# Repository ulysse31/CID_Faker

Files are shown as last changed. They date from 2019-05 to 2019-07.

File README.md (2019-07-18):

# DISCLAIMER :
# THIS PROJECT IS A PATCH MADE BY MYSELF, FOR MYSELF, AND IT AIMS TO COMPENSATE, THE LACK OF BUG CORRECTIONS IN THIRD PARTY REPLACEMENT SCREENS (CHINESE ANDROID BASED SCREENS) THAT DO NOT HAVE IMPLEMENTED THIS PARTICULAR CASE ON THEIR MCU FIRMWARE...

# WARNING !!! WE ARE TALKING ABOUT INJECTING DATA TO THE CAR NETWORK, THIS IS AT YOUR OWN RISK !!! I WILL NOT BE RESPONSIBLE FOR ANY HARM YOU MAY CAUSE TO YOUR CAR, YOURSELF, OR ANY OTHER
# YOU HAVE BEEN WARNED !!!
# CID_Faker
A CID can bus simulator:

CID (Central Information Display) on BMW cars from 2004 to 2011 is the designation for the car LCD screen.
Some of those screens are connected to the can bus of the car (at least BMW flap screens).
If you try to replace this type of screen with something else (like an Android Head Unit) you'll loose the ability to 
interact with the BMW original menu (no actions from idrive interpreted).

This project supposes that this is because of the absence of the can message id from the screen : "why take into
account moves from idrive if no screen detected" ... thats what the engineer may have thought when implementing this
on the CCC controller ...

This little code will so generate fake CID id messages on the can bus of the car, to simulate the presence of the CID.
CID sends messages with id 0x33a (status) and 0x4f3 (network).
All the main job will be to find the right messages, their combinations and timings.

Project uses platformIO for easy compilation and development.

For now, I'm using a Pro Micro board 5V@16Mhz, and a well known MCP2515 CAN Controller module, more precisely the
MCP2515 CAN controller with a 8Mhz oscillator and TJA1050 CAN transceiver.

You'll find on "Hardware" folder 2 types of designs :

- USB_Powered (tested working/recommended): this light version aims to be connected to the Android HU on its USB port, allowing it to be
powered up once the Android is up (key car inserted), and powered off when Android goes off (key car taken out)

- Standalone (not tested/under construction): this version aims to be more "unrelated" the Android HU, it is up the user to find a power
cable source from the car (preferrably, a source that is NOT always on ...)

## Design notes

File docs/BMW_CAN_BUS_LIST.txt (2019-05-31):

CAN_ID_HEX	CAN_ID_NAME	CAN_ID_NAME (Translated)	DIAG_ID_HEX	SG_NAME
0x00	unbekannt	unknown	0x00	Sender unbekannt
0xA8	Drehmoment 1 K-CAN [10]	Torque 1 K-CAN [10]	0x12	DME1/DDE1
0xA9	Drehmoment 2 (10)	Torque 2 (10)	0x12	DME1/DDE1
0xAA	Drehmoment 3 K-CAN [10]	Torque 3 K-CAN [10]	0x12	DME1/DDE1
0xAC	Radmoment Antriebsstrang 2 [5]	Wheel torque Drive train 2 [5]	0x12	DME1/DDE1
0xAD	Verzögerungsanforderung ACC [9]	Delay request ACC [9]	0x1C	LDM
0xAD	Verzögerungsanforderung ACC [9]	Delay request ACC [9]	0x21	ACC_Modul/ACC+NAVI
0xB3	Steuerung Lenkunterstützung [2]	Steering assistance steering [2]	0x16	AFS
0xB4	Radmoment Antriebsstrang 1 [4]	Wheel torque Drive train 1 [4]	0x12	DME1/DDE1
0xB5	Drehmomentanforderung EGS [9]	Torque demand EGS [9]	0x18	EGS_MECH+NAVI/EGS_MECH
0xB6	Drehmomentanforderung DSC [7]	Torque demand DSC [7]	0x29	DXC_RB/DSC_RB/DSC_CT
0xB7	Drehmomentanforderung ACC [10]	Torque demand ACC [10]	0x1C	LDM
0xB7	Drehmomentanforderung ACC [10]	Torque demand ACC [10]	0x21	ACC_Modul/ACC+NAVI
0xB8	Drehmomentanforderung DKG [2]	Torque requirement DKG [2]	0x18	DKG
0xB9	Drehmomentanforderung AFS [3]	Torque demand AFS [3]	0x16	AFS
0xBA	Getriebedaten [20]	Transmission data [20]	0x18	SMG_M/SMG/EGS_MECH+NAVI/EGS_MECH/DKG
0xBB	Sollmomentanforderung [7]	Required torque request [7]	0x29	DXC_RB
0xBC	Status Sollmomentumsetzung [7]	Status setpoint torque conversion [7]	0x19	VGSG
0xBD	Drehmomentanforderung SSG [6]	Torque demand SSG [6]	0x18	SMG_M/SMG
0xBE	Alive Zähler [12]	Alive counters [12]	0x23	ARS_Modul
0xBF	Anforderung Radmoment Antriebsstrang [6]	Requirement wheel torque Drive train [6]	0x1C	LDM
0xC0	Alive Zentrales Gateway [1]	Alive Central Gateway [1]	0x0	KGM
0xC1	Alive Zähler Telefon [3]	Alive counter phone [3]	0x36	TEL_JAP/TEL_BPI
0xC4	Lenkradwinkel K-CAN [13]	Steering wheel angle K-CAN [13]	0x29	DXC_RB/DSC_RB/DSC_CT
0xC8	Lenkradwinkel Oben K-CAN [6]	Steering wheel angle Top K-CAN [6]	0x2	SZL_LWS
0xCE	Radgeschwindigkeit K-CAN [4]	Wheel speed K-CAN [4]	0x29	DXC_RB/DSC_RB/DSC_CT
0xD2	Bedienung Sitzverstellung BF [6]	Operation Seat adjustment BF [6]	0x65	SZM_MIT_KBUS/SZM
0xD5	Anforderung Radmoment Bremse [6]	Wheel torque brake requirement [6]	0x1C	LDM
0xD7	Alive Zähler Sicherheit [2]	Alive counter security [2]	0x1	ACSM
0xDA	Bedienung Sitzverstellung FA [6]	Operation Seat adjustment FA [6]	0x65	SZM_MIT_KBUS/SZM
0xE1	Radmoment Bremse [3]	Wheel torque brake [3]	0x29	DXC_RB/DSC_RB
0xE2	Status Zentralverriegelung BFT [11]	Status Central locking system BFT [11]	0x0	KGM
0xE6	Status Zentralverriegelung BFTH [11]	Status Central locking BFTH [11]	0x72	KBM
0xEA	Status Zentralverriegelung FAT [11]	Status Central locking FAT [11]	0x0	KGM
0xEE	Status Zentralverriegelung FATH [11]	Status Central locking FATH [11]	0x72	KBM
0xF2	Status Zentralverriegelung HK [13]	Status Central locking HK [13]	0x72	KBM
0xF6	Steuerung Außenspiegel [9]	Steering wheel mirrors [9]	0x0	KGM
0xFA	Steuerung Fensterheber FAT [10]	Control window lifters FAT [10]	0x0	KGM
0xFB	Steuerung Fensterheber BFT [5]	Control window lifters BFT [5]	0x0	KGM
0xFC	Steuerung Fensterheber FATH [5]	FATH Control Window Regulators [5]	0x72	KBM
0xFD	Steuerung Fensterheber BFTH [5]	Control window lifters BFTH [5]	0x72	KBM
0x130	Klemmenstatus [19]	Terminal status [19]	0x40	CAS
0x135	Steuerung Crashabschaltung EKP [1]	Control Crash Disconnection EKP [1]	0x1	ACSM
0x15F	Anforderung Winkel FFP [6]	Request angle FFP [6]	0x1C	LDM
0x172	Quittierung Anforderung Kombi [1]	Acknowledgment request Combi [1]	0x62	M_ASK/CCC_GW
0x190	Anzeige ACC [13]	Display ACC [13]	0x1C	LDM
0x190	Anzeige ACC [13]	Display ACC [13]	0x21	ACC_Modul/ACC+NAVI
0x192	Bedienung Getriebewahlschalter [16]	Operation Gear selector switch [16]	0x2	SZL_LWS
0x193	Anzeige ACC DCC [4]	Display ACC DCC [4]	0x1C	LDM
0x194	Bedienung Tempomat/ACC [13]	Operation Tempomat / ACC [13]	0x2	SZL_LWS
0x198	Bedienung Getriebewahlschalter 2 [2]	Operation Gear selector switch 2 [2]	0x5E	GWS
0x19E	Status DSC K-CAN [19]	Status DSC K-CAN [19]	0x29	DXC_RB/DSC_RB/DSC_CT
0x1A0	Geschwindigkeit K-CAN [14]	Speed K-CAN [14]	0x29	DXC_RB/DSC_RB/DSC_CT
0x1A2	Getriebedaten 2 [6]	Transmission data 2 [6]	0x18	EGS_MECH+NAVI/EGS_MECH/DKG
0x1A3	Rohdaten Längsbeschleunigung [3]	Raw data longitudinal acceleration [3]	0x18	SMG_M
0x1A6	Wegstrecke [6]	Distance [6]	0x29	DXC_RB/DSC_RB/DSC_CT
0x1AA	Effekt ErgoCommander [10]	Effect ErgoCommander [10]	0x62	M_ASK/CCC_GW
0x1AC	Status ARS-Modul [13]	Status ARS module [13]	0x23	ARS_Modul
0x1B4	Status Kombi [14]	Status Combine [14]	0x60	Kombi
0x1B5	Wärmestrom/Lastmoment Klima [14]	Heat flow / load moment Climate [14]	0x78	IHKA
0x1B6	Wärmestrom Motor [11]	Heat flow motor [11]	0x12	DME1/DDE1
0x1B8	Bedienung ErgoCommander [6]	Operation ErgoCommander [6]	0x67	ZBE_LO/ZBE
0x1C2	Abstandsmeldung PDC [5]	Distance indication PDC [5]	0x64	PDC
0x1C3	Abstandsmeldung 2 PDC [3]	Distance indication 2 PDC [3]	0x64	PDC
0x1C6	Akustikmeldung PDC [5]	Acoustic message PDC [5]	0x64	PDC
0x1D0	Motordaten [13]	Motor data [13]	0x12	DME1/DDE1
0x1D2	Anzeige Getriebedaten [22]	Transmission data display [22]	0x18	SMG_M/SMG/EGS_MECH+NAVI/EGS_MECH/DKG
0x1D6	Bedienung Taster Audio/Telefon [12]	Audio / phone control buttons [12]	0x2	SZL_LWS
0x1D8	Bedienung Klima Luftverteilung FA [13]	Operation Climate air distribution FA [13]	0x62	M_ASK/CCC_GW
0x1D9	Bedienung Taster M-Drive [2]	Operating buttons M-Drive [2]	0x2	SZL_LWS
0x1DA	Bedienung Klima Fernwirken [5]	Operation Climate Telecontrol [5]	0x40	CAS
0x1DC	Bedienung Schichtung Sitzheizung [1]	Operation layering Seat heating [1]	0x62	M_ASK/CCC_GW
0x1E0	Bedienung Klima Luftverteilung BF [7]	Operation Climate air distribution BF [7]	0x62	M_ASK/CCC_GW
0x1E2	Bedienung Klima Front [11]	Operation Climate Front [11]	0x62	M_ASK/CCC_GW
0x1E7	Bedienung Sitzheizung/Sitzklima FA [7]	Operation seat heating / seat climate FA [7]	0x65	SZM_MIT_KBUS/SZM
0x1E8	Bedienung Sitzheizung/Sitzklima BF [7]	Operation seat heating / seating climate BF [7]	0x65	SZM_MIT_KBUS/SZM
0x1EA	Bedienung Lenksäulenverstellung [5]	Operation Steering column adjustment [5]	0x2	SZL_LWS
0x1EB	Bedienung Aktivsitz FA [3]	Operation Active seat FA [3]	0x65	SZM_MIT_KBUS/SZM
0x1EC	Bedienung Aktivsitz BF [3]	Operation Active seat BF [3]	0x65	SZM_MIT_KBUS/SZM
0x1ED	Bedienung Lehnenbreitenverstellung Aktiv FA [2]	Operation of the backrest width adjustment active FA [2]	0x65	SZM_MIT_KBUS/SZM
0x1EE	Bedienung Lenkstockstaster [6]	Steering wheel control [6]	0x2	SZL_LWS
0x1EF	Bedienung Lehnenbreitenverstellung Aktiv BF [2]	Operation Backrest width adjustment Active BF [2]	0x65	SZM_MIT_KBUS/SZM
0x1F2	Bedienung Sitzmemory BF [3]	Operation Seat memory BF [3]	0x65	SZM_MIT_KBUS/SZM
0x1F3	Bedienung Sitzmemory FA [4]	Operation Seatmemory FA [4]	0x65	SZM_MIT_KBUS/SZM
0x1F4	Fernbedienung Sitzmemory BF [2]	Remote Control Seat Memory BF [2]	0xFF	unbekannt
0x1F6	Blinken [6]	Flashing [6]	0x70	LM
0x1FC	Status AFS [4]	Status AFS [4]	0x16	AFS
0x1FE	Crash [12]	Crash [12]	0x1	ACSM
0x200	Regelgeschwindigkeit Stufentempomat [7]	Speed regulation [7]	0x12	DME1/DDE1
0x202	Dimmung [10]	Dimming [10]	0x70	LM
0x205	Akustikanforderung Kombi [3]	Acoustic demand combination [3]	0x60	Kombi
0x206	Steuerung Anzeige Shiftlights [1]	Control Display Shiftlights [1]	0x12	DME1
0x20B	Memoryverstellung [6]	Memory adjustment [6]	0x65	SZM_MIT_KBUS
0x20B	Memoryverstellung [6]	Memory adjustment [6]	0x6D	SM_FA
0x20C	Steuerung Lenksäule (4)	Steering Column Control (4)	0x6D	SM_FA
0x20D	Position Lenksäule (5)	Position steering column (5)	0x65	SZM_MIT_KBUS/SZM
0x210	Bedienung HUD [7]	Operation HUD [7]	0x62	M_ASK/CCC_GW
0x211	Status HUD [7]	Status HUD [7]	0x3D	HUD
0x212	Höhenstände Luftfeder [8]	Height air spring [8]	0x38	EHC
0x21A	Lampenzustand [13]	Lamp condition [13]	0x70	LM
0x21C	Bedienung Night-Vision [2]	Operation Night-Vision [2]	0x62	CCC_GW
0x21E	Status Night-Vision [2]	Status Night-Vision [2]	0x57	NVC
0x226	Regensensor-Wischergeschwindigkeit [8]	Rain sensor wiper speed [8]	0x45	RLS
0x226	Regensensor-Wischergeschwindigkeit [8]	Rain sensor wiper speed [8]	0x70	LM
0x228	Bedienung Sonderfunktion [8]	Operation special function [8]	0x62	M_ASK/CCC_GW
0x228	Bedienung Sonderfunktion [8]	Operation special function [8]	0x63	CCC_MM
0x22A	Status BFS [10]	Status FSO [10]	0x6E	SM_BF
0x22E	Status BFSH [7]	Status BFSH [7]	0xFF	unbekannt
0x232	Status FAS [10]	Status FAS [10]	0x6D	SM_FA
0x236	Status FASH [7]	Status FASH [7]	0xFF	unbekannt
0x237	Status Lehnenbreitenverstellung Aktiv BF [3]	Status Backrest width adjustment Active BF [3]	0x5A	aLBV_BF
0x239	Status Lehnenbreitenverstellung Aktiv FA [3]	Status Backrest width adjustment Active FA [3]	0x59	aLBV_FA
0x23A	Status Funkschlüssel [13]	Status radio key [13]	0x40	CAS
0x23B	Status Klima Front Erweitert [1]	Status Climate Front Advanced [1]	0x78	IHKA
0x23C	Status Bedienung Sitzkomfort FA [1]	Status Operation Seating comfort FA [1]	0x6D	SM_FA
0x23F	Status Bedienung Sitzkomfort BF [1]	Status Operating Seating Comfort BF [1]	0x6E	SM_BF
0x242	Status Klima Front [11]	Status Climate Front [11]	0x78	IHKA
0x24A	Status PDC [6]	Status PDC [6]	0x64	PDC
0x252	Wischerstatus [8]	Wiper status [8]	0x72	KBM
0x256	Challenge Passive Access [10]	Challenge Passive Access [10]	0x40	CAS
0x258	Status Transmission Passive Access [4]	Status Transmission Passive Access [4]	0x27	PGS
0x25C	Bedienung Klima Zusatzprogramme [2]	Operating climate Additional programs [2]	0x62	M_ASK/CCC_GW
0x26B	Bedienung Rollos BF [2]	Operation Roller blinds BF [2]	0xFF	unbekannt
0x26C	Bedienung Rollos FA [2]	Operation Roller blinds FA [2]	0x0	KGM
0x26D	Bedienung Rollos MK [1]	Operation Roller blinds MK [1]	0xFF	unbekannt
0x26E	Steuerung FH/SHD Zentrale (Komfort) [10]	Control FH / SHD Central (Comfort) [10]	0x40	CAS
0x26F	Bedienung Rollos BFH [2]	Operation Roller blinds BFH [2]	0xFF	unbekannt
0x270	Bedienung Rollos FAH [2]	Operation Roller blinds FAH [2]	0xFF	unbekannt
0x278	Navigationsgraph [3]	Navigation chart [3]	0x62	CCC_GW
0x27A	Synchronisation Navigationsgraph [4]	Synchronization navigation graph [4]	0x62	CCC_GW
0x27E	Status Verdeck Cabrio [7]	Convertible top convertible top [7]	0x24	CVM_V
0x284	Steuerung Fernstart Sicherheitsfahrzeug [8]	Remote control starter safety [8]	0x40	CAS
0x285	Steuerung Rollos [3]	Control roller blinds [3]	0x65	SZM_MIT_KBUS/SZM
0x28C	Bedienung Taster Vertikaldynamik [2]	Control buttons Vertical Dynamics [2]	0x5E	GWS
0x290	Steuerung Reaktion Wasserstoff-Fahrzeug [1]	Control reaction Hydrogen vehicle [1]	0xFF	unbekannt
0x292	Steuerung Fernlicht-Assistent [2]	Steering Wheel Assistant [2]	0x5F	FLA
0x29F	Fernbedienung FondCommander [5]	Remote Control FondCommander [5]	0x40	CAS
0x2A0	Steuerung Zentralverriegelung [10]	Central locking control [10]	0x40	CAS
0x2A2	Bedienung Klima Standfunktionen [5]	Operation Air conditioner [5]	0x62	M_ASK/CCC_GW
0x2A4	Bedienung Personalisierung [8]	Operation Personalization [8]	0x62	M_ASK/CCC_GW
0x2A6	Bedienung Wischertaster [12]	Operation Wiper switch [12]	0x2	SZL_LWS
0x2B2	Raddrücke K-CAN [1]	Wheel pressure K-CAN [1]	0x29	DXC_RB/DSC_RB/DSC_CT
0x2B3	Beschleunigungsdaten [2]	Acceleration data [2]	0x29	DXC_RB/DSC_RB/DSC_CT
0x2B4	DWA-Alarm [4]	DWA alarm [4]	0x41	DWA
0x2B6	Steuerung Hupe DWA [3]	Control horn DWA [3]	0x41	DWA
0x2B8	Bedienung Bordcomputer [3]	Operation board computer [3]	0x62	M_ASK/CCC_GW
0x2BA	Stoppuhr (3)	Stopwatch (3)	0x60	Kombi
0x2C0	LCD-Leuchtdichte [7]	LCD lighting [7]	0x60	Kombi
0x2CA	Außentemperatur [9]	Outdoor temperature [9]	0x60	Kombi
0x2CE	Steuerung Monitor [4]	Control monitor [4]	0x62	M_ASK/CCC_GW
0x2D5	Status Heizung Heckscheibe [1]	Status Heating rear window [1]	0x78	IHKA
0x2DA	Status Heckklappenlift [2]	Status of tailgate lift [2]	0x6B	HKL
0x2E2	Status Einstellung Video Night-Vision [1]	Status Setting Video Night-Vision [1]	0x57	NVC
0x2E4	Status Anhänger (8)	Status Trailers (8)	0x71	AHM
0x2E6	Status Klima Luftverteilung FA [13]	Status Climate air distribution FA [13]	0x78	IHKA
0x2EA	Status Klima Luftverteilung BF [9]	Status Climate air distribution BF [9]	0x78	IHKA
0x2EC	Status Klima SH/ZH Zusatzwasserpumpe [14]	Status Climate SH / ZH Additional water pump [14]	0x7A	SH_ZH
0x2EE	Status Klima Zusatzprogramme [2]	Status of climate supplementary programs [2]	0x78	IHKA
0x2F0	Status Klima Standfunktionen [12]	Status of climate status [12]	0x78	IHKA
0x2F4	Steuerung Klima SH/ZH Zusatzwasserpumpe [13]	Control climate SH / ZH auxiliary water pump [13]	0x78	IHKA
0x2F6	Steuerung Licht [7]	Control light [7]	0x72	KBM
0x2F7	Einheiten [10]	Units [10]	0x62	M_ASK/CCC_GW
0x2F7	Einheiten [10]	Units [10]	0x63	CCC_MM
0x2F8	Uhrzeit/Datum [12]	Time / Date [12]	0x60	Kombi
0x2FA	Sitzbelegung Gurtkontakte (14)	Seat belt contact (14)	0x1	ACSM
0x2FC	ZV und Klappenzustand [11]	ZV and folding condition [11]	0x40	CAS
0x304	Status Gang [13]	Status Status [13]	0x18	SMG_M/SMG/EGS_MECH+NAVI/EGS_MECH/DKG
0x306	Fahrzeugneigung [2]	Towing	0x70	LM
0x308	Status MSA [2]	Status MSA [2]	0x12	DME1/DDE1
0x310	Außentemperatur/Relativzeit [10]	External temperature / relative time [10]	0x60	Kombi
0x311	Nachtankmenge [3]	Nightfall [3]	0x60	Kombi
0x312	Service Call Teleservice [2]	Service Call Teleservice [2]	0x60	Kombi
0x313	Status Service Call Teleservice [3]	Status Service Call Teleservice [3]	0x36	TEL_BPI
0x313	Status Service Call Teleservice [3]	Status Service Call Teleservice [3]	0x62	M_ASK/CCC_GW
0x314	Status Fahrlicht [9]	Status of driving light [9]	0x45	RLS
0x314	Status Fahrlicht [9]	Status of driving light [9]	0x70	LM
0x315	Fahrzeugmodus [7]	Vehicle mode [7]	0x65	SZM_MIT_KBUS/SZM
0x317	Bedienung Taster PDC [1]	Operation button PDC [1]	0x65	SZM_MIT_KBUS/SZM
0x318	Status Antennen Passive Access [7]	Status Antennas Passive Access [7]	0x27	PGS
0x319	Bedienung Taster RDC [4]	Operation button RDC [4]	0x65	SZM
0x31C	Status Reifendruck [6]	Status of tire pressure [6]	0x20	RDC
0x31D	Status Reifenpannenanzeige [6]	Status of tire tension indicator [6]	0x29	DXC_RB/DSC_RB/DSC_CT
0x322	Dämpferstrom [2]	Damp current [2]	0x39	EDCK_Modul
0x326	Status Dämpferprogramm [9]	Status damper program [9]	0x39	EDCK_Modul
0x328	Relativzeit [9]	Relative time [9]	0x60	Kombi
0x32A	Steuerung ALC [2]	Control system ALC [2]	0x70	LM
0x32D	Anzeige HDC [3]	Display HDC [3]	0x29	DXC_RB
0x32E	Status Klima Interne Regelinfo [6]	Status Climate Internal Ruleinfo [6]	0x78	IHKA
0x330	Kilometerstand/Reichweite [5]	Mileage / range [5]	0x60	Kombi
0x331	Programmierung Stufentempomat [2]	Programming step stepping [2]	0x62	M_ASK/CCC_GW
0x332	Fahreranzeige Drehzahlbereich [4]	Driver display Speed range [4]	0x12	DME1/DDE1
0x335	Status Elektrische Kraftstoffpumpe [3]	Status Electric Fuel Pump [3]	0x17	EKP
0x336	Anzeige Checkcontrol-Meldung (Rolle) [3]	Display of checkcontrol message (role) [3]	0x60	Kombi
0x337	Status Kraftstoffregelung DME [1]	Status Fuel Control DME [1]	0x12	DME1
0x338	Steuerung Anzeige Checkcontrol-Meldung [7]	Control display Checkcontrol message [7]	0x60	Kombi
0x339	Status Anzeige Funktionen Extern [1]	Status Display Functions External [1]	0x62	M_ASK/CCC_GW
0x33A	Status Monitor Front [3]	Status Monitor Front [3]	0x73	CID_C_H/CID_C
0x348	Übereinstimmung Navigationsgraph [4]	Conformity navigation graph [4]	0x62	CCC_GW
0x34A	Navigation GPS 1 [5]	Navigation GPS 1 [5]	0x62	CCC_GW
0x34B	Status Sitzlehnenverriegelung FA (3)	Status Seat back rest FA (3)	0x65	SZM_MIT_KBUS
0x34B	Status Sitzlehnenverriegelung FA (3)	Status Seat back rest FA (3)	0x6D	SM_FA
0x34C	Navigation GPS 2 [5]	Navigation GPS 2 [5]	0x62	CCC_GW
0x34D	Status Sitzlehnenverriegelung BF [2]	Status Seat backrest BF [2]	0x65	SZM_MIT_KBUS
0x34D	Status Sitzlehnenverriegelung BF [2]	Status Seat backrest BF [2]	0x6E	SM_BF
0x34E	Navigation System Information [6]	Navigation system information [6]	0x62	CCC_GW
0x35A	Termin Condition Based Service [2]	Appointment Condition Based Service [2]	0x62	M_ASK/CCC_GW
0x35C	Status Bordcomputer [5]	Status of board computer [5]	0x60	Kombi
0x35E	Daten Bordcomputer (Reisedaten) [5]	Data on board computer (rice data) [5]	0x60	Kombi
0x360	Daten Bordcomputer (Fahrtbeginn) [2]	Data board computer (start of journey) [2]	0x60	Kombi
0x362	Daten Bordcomputer (Durchschnittswerte) [4]	Data on board computer (average values) [4]	0x60	Kombi
0x364	Daten Bordcomputer (Ankunft) [2]	Data board computer (arrival) [2]	0x60	Kombi
0x366	Anzeige Kombi/Externe Anzeige [3]	Display Combi / External Display [3]	0x60	Kombi
0x367	Steuerung Anzeige Bedarfsorientierter Service [6]	Control Display Demand-oriented Service [6]	0x60	Kombi
0x374	Radtoleranzabgleich [7]	Wheel tolerance adjustment [7]	0x29	DXC_RB/DSC_RB/DSC_CT
0x376	Status Verschleiß Lamelle [3]	Status wear lamella [3]	0x19	VGSG
0x380	Fahrgestellnummer [5]	Chassis number [5]	0x40	CAS
0x381	Elektronischer Motorölmessstab [10]	Electronic engine oil dipstick [10]	0x12	DME1/DDE1
0x382	Elektronischer Motorölmessstab M [1]	Electronic engine oil dipstick M [1]	0x12	DME1/DDE1
0x388	Fahrzeugtyp [13]	Vehicle type [13]	0x40	CAS
0x38E	Startdrehzahl [1]	Starting speed [1]	0x12	DME1/DDE1
0x394	RDA Anfrage/Datenablage [5]	RDA Request / Data Storage [5]	0x60	Kombi
0x395	Codierung Powermanagement [2]	Coding Powermanagement [2]	0x40	CAS
0x398	Bedienung Fahrwerk [14]	Operation Chassis [14]	0x62	M_ASK/CCC_GW
0x399	Status M-Drive [2]	Status M-Drive [2]	0x12	DME1
0x39C	EBA Datenanforderung [5]	EBA data request [5]	0xFF	unbekannt
0x39E	Bedienung Uhrzeit/Datum [1]	Operation Time / Date [1]	0x62	M_ASK/CCC_GW
0x3A0	Fahrzeugzustand [4]	Vehicle condition [4]	0x0	KGM
0x3A3	Anforderung Remote Services [2]	Request Remote Services [2]	0x62	M_ASK/CCC_GW
0x3AC	Nachlaufzeit Klemme 30 fehlergesteuert [2]	Follow-up time Terminal 30 error-controlled [2]	0x0	KGM
0x3B0	Status Gang Rückwärts [2]	Status Reverse [2]	0x70	LM
0x3B1	Getriebedaten 3 [2]	Transmission data 3 [2]	0x18	EGS_MECH/DKG
0x3B3	Powermanagement Verbrauchersteuerung [8]	Powermanagement Consumer Control [8]	0x12	DME1/DDE1
0x3B4	Powermanagement Batteriespannung [11]	Powermanagement Battery voltage [11]	0x12	DME1/DDE1
0x3B5	Status Wasserventil [6]	Status Water valve [6]	0x78	IHKA
0x3B6	Position Fensterheber FAT [6]	Position window lifter FAT [6]	0x0	KGM
0x3B7	Position Fensterheber FATH [5]	Position window lifters FATH [5]	0x72	KBM
0x3B8	Position Fensterheber BFT [6]	Position window lifter BFT [6]	0x0	KGM
0x3B9	Position Fensterheber BFTH [5]	Position Window lifters BFTH [5]	0x72	KBM
0x3BA	Position SHD [10]	Position SHD [10]	0x44	SHD/MDS
0x3BD	Status Verbraucherabschaltung [2]	Status of consumer disconnection [2]	0x72	KBM
0x3BE	Nachlaufzeit Stromversorgung [5]	Run-on time Power supply [5]	0x40	CAS
0x3BF	Position Fensterheber Heckscheibe [1]	Position Window Regulator Rear Window [1]	0x24	CVM_V
0x3C0	Konfiguration FAS [3]	Configuration FAS [3]	0x6D	SM_FA
0x3C1	Konfiguration BFS [3]	Configuration FSO [3]	0x6E	SM_BF
0x3CA	Konfiguration M-Drive [2]	Configuration M-Drive [2]	0x62	M_ASK/CCC_GW
0x3D3	Status Solarsensor [1]	Status Solar sensor [1]	0x70	LM
0x3D4	Konfiguration Zentralverriegelung CKM [3]	Configuration Central locking CKM [3]	0x62	M_ASK/CCC_GW
0x3D5	Status Zentralverriegelung CKM [4]	Status Central locking CKM [4]	0x40	CAS
0x3D6	Konfiguration DWA CKM [1]	Configuration DWA CKM [1]	0x62	M_ASK/CCC_GW
0x3D7	Status DWA CKM [2]	Status DWA CKM [2]	0x41	DWA
0x3D8	Konfiguration RLS CKM [3]	Configuration RLS CKM [3]	0x62	M_ASK/CCC_GW
0x3D9	Status RLS CKM [4]	Status RLS CKM [4]	0x45	RLS
0x3D9	Status RLS CKM [4]	Status RLS CKM [4]	0x70	LM
0x3DA	Konfiguration Memorypositionen CKM [1]	Configuration Memory positions CKM [1]	0x62	M_ASK/CCC_GW
0x3DB	Status Memorypositionen CKM [3]	Status Memory positions CKM [3]	0x65	SZM_MIT_KBUS
0x3DB	Status Memorypositionen CKM [3]	Status Memory positions CKM [3]	0x6D	SM_FA
0x3DC	Konfiguration Licht CKM [3]	Configuration light CKM [3]	0x62	M_ASK/CCC_GW
0x3DD	Status Licht CKM [4]	Status light CKM [4]	0x70	LM
0x3DE	Konfiguration Klima CKM [5]	Configuration Climate CKM [5]	0x62	M_ASK/CCC_GW
0x3DF	Status Klima CKM [6]	Status Climate CKM [6]	0x78	IHKA
0x3E0	Konfiguration ALC CKM [1]	Configuration ALC CKM [1]	0x62	M_ASK/CCC_GW
0x3E1	Status ALC CKM [1]	Status ALC CKM [1]	0x70	LM
0x3E2	Konfiguration Heckklappe CKM [1]	Configuration tailgate CKM [1]	0x62	M_ASK/CCC_GW
0x3E3	Status Heckklappe CKM [1]	Status tailgate CKM [1]	0x6B	HKL
0x3E9	Marker 1 [1]	Marker 1 [1]	0xFF	unbekannt
0x3EA	Marker 2 [3]	Marker 2 [3]	0x7E	Diagnosetool_K_CAN_System
0x3EB	Marker 3 [1]	Marker 3 [1]	0x7D	Diagnosetool_PT_CAN
0x3EE	Anforderung Fehlermeldung [1]	Request error message [1]	0xFF	unbekannt
0x3EF	OBD Daten Motor (3)	OBD data engine (3)	0x12	DME1/DDE1
0x3F0	Konfiguration Licht Erweitert CKM [1]	Configuration Light Advanced CKM [1]	0x62	M_ASK/CCC_GW
0x3F1	Status Licht Erweitert CKM [1]	Status Light Advanced CKM [1]	0x70	LM
0x3F4	Konfiguration Laderaumabdeckung CKM [1]	Configuration of charger cover CKM [1]	0x62	M_ASK/CCC_GW
0x3F5	Status Laderaumabdeckung CKM [1]	Status Charging compartment cover CKM [1]	0x72	KBM
0x3FE	Anforderung CAN_Testtool SI-Bus [5]	Requirement CAN_Testtool SI-Bus [5]	0x7E	Diagnosetool_K_CAN_System
0x480	Netzwerkmanagement	Network management	0x0	KGM
0x481	Netzwerkmanagement	Network management	0x1	ACSM
0x482	Netzwerkmanagement	Network management	0x2	SZL_LWS
0x492	Netzwerkmanagement	Network management	0x12	DDE1/DME1
0x496	Netzwerkmanagement	Network management	0x16	AFS
0x497	Netzwerkmanagement	Network management	0x17	EKP
0x498	Netzwerkmanagement	Network management	0x18	DKG/EGS_MECH/EGS_MECH+NAVI/SMG/SMG_M
0x499	Netzwerkmanagement	Network management	0x19	VGSG
0x49B	Netzwerkmanagement	Network management	0x1B	VVT1
0x49C	Netzwerkmanagement	Network management	0x1C	LDM
0x49E	Netzwerkmanagement	Network management	0x1E	VVT2
0x4A0	Netzwerkmanagement	Network management	0x20	RDC
0x4A1	Netzwerkmanagement	Network management	0x21	ACC+NAVI/ACC_Modul
0x4A3	Netzwerkmanagement	Network management	0x23	ARS_Modul
0x4A4	Netzwerkmanagement	Network management	0x24	CVM_V
0x4A5	Netzwerkmanagement	Network management	0x25	RSC_VDA/SC_CT/SC_VDA
0x4A7	Netzwerkmanagement	Network management	0x27	PGS
0x4A9	Netzwerkmanagement	Network management	0x29	DSC_CT/DSC_RB/DXC_RB
0x4B6	Netzwerkmanagement	Network management	0x36	TEL_BPI/TEL_JAP/TEL_MULF
0x4B7	Netzwerkmanagement	Network management	0x37	AMP_TOP
0x4B8	Netzwerkmanagement	Network management	0x38	EHC
0x4B9	Netzwerkmanagement	Network management	0x39	EDCK_Modul
0x4BA	Netzwerkmanagement	Network management	0x3A	KHM
0x4BB	Netzwerkmanagement	Network management	0x3B	JNAV
0x4BC	Netzwerkmanagement	Network management	0x3C	CDC
0x4BD	Netzwerkmanagement	Network management	0x3D	HUD
0x4C0	Netzwerkmanagement	Network management	0x40	CAS
0x4C1	Netzwerkmanagement	Network management	0x41	DWA
0x4C4	Netzwerkmanagement	Network management	0x44	MDS/SHD
0x4C5	Netzwerkmanagement	Network management	0x45	RLS/RLS
0x4CB	Netzwerkmanagement	Network management	0x4B	VM
0x4D0	Netzwerkmanagement	Network management	0x50	Notstrom-Sirene
0x4D3	Netzwerkmanagement	Network management	0x53	IBOC
0x4D4	Netzwerkmanagement	Network management	0x54	SDARS
0x4D5	Netzwerkmanagement	Network management	0x55	ISpeechBox
0x4D7	Netzwerkmanagement	Network management	0x57	NVC
0x4D9	Netzwerkmanagement	Network management	0x59	aLBV_FA
0x4DA	Netzwerkmanagement	Network management	0x5A	aLBV_BF
0x4DB	Netzwerkmanagement	Network management	0x5B	DAB
0x4DC	Netzwerkmanagement	Network management	0x5C	Behoerde
0x4DD	Netzwerkmanagement	Network management	0x5D	TLC
0x4DE	Netzwerkmanagement	Network management	0x5E	GWS
0x4DF	Netzwerkmanagement	Network management	0x5F	FLA
0x4E0	Netzwerkmanagement	Network management	0x60	Kombi
0x4E2	Netzwerkmanagement	Network management	0x62	CCC_GW/M_ASK
0x4E3	Netzwerkmanagement	Network management	0x63	CCC_MM
0x4E4	Netzwerkmanagement	Network management	0x64	PDC
0x4E5	Netzwerkmanagement	Network management	0x65	SZM/SZM_MIT_KBUS
0x4E7	Netzwerkmanagement	Network management	0x67	ZBE/ZBE_LO
0x4EB	Netzwerkmanagement	Network management	0x6B	HKL
0x4ED	Netzwerkmanagement	Network management	0x6D	SM_FA/SM_FA_KBUS
0x4EE	Netzwerkmanagement	Network management	0x6E	SM_BF/SM_BF_KBUS
0x4F0	Netzwerkmanagement	Network management	0x70	LM/LM_ALC
0x4F1	Netzwerkmanagement	Network management	0x71	AHM
0x4F2	Netzwerkmanagement	Network management	0x72	KBM
0x4F3	Netzwerkmanagement	Network management	0x73	CID_C/CID_C_H
0x4F8	Netzwerkmanagement	Network management	0x78	IHKA
0x4FA	Netzwerkmanagement	Network management	0x7A	SH_ZH
0x4FD	Netzwerkmanagement	Network management	0x7D	Diagnosetool_PT_CAN
0x4FE	Netzwerkmanagement	Network management	0x7E	Diagnosetool_K_CAN_System
0x500	Datentransfer [1]	Data transfer [1]	0x70	LM
0x500	Datentransfer [1]	Data transfer [1]	0x78	IHKA
0x509	Netzwerkmanagement	Network management	0x89	Xenon_Scheinwerfer_Links_ALC
0x50A	Netzwerkmanagement	Network management	0x8A	Xenon_Scheinwerfer_Rechts_ALC
0x50B	Netzwerkmanagement	Network management	0x8B	CNV
0x571	Netzwerkmanagement	Network management	0xF1	Diagnosedose
0x580	Dienste	services	0x0	KGM
0x581	Dienste	services	0x1	ACSM
0x582	Dienste	services	0x2	SZL_LWS
0x592	Dienste	services	0x12	DDE1/DME1
0x596	Dienste	services	0x16	AFS
0x597	Dienste	services	0x17	EKP
0x598	Dienste	services	0x18	DKG/EGS_MECH/EGS_MECH+NAVI/SMG/SMG_M
0x599	Dienste	services	0x19	VGSG
0x59B	Dienste	services	0x1B	VVT1
0x59C	Dienste	services	0x1C	LDM
0x59E	Dienste	services	0x1E	VVT2
0x5A0	Dienste	services	0x20	RDC
0x5A1	Dienste	services	0x21	ACC+NAVI/ACC_Modul
0x5A3	Dienste	services	0x23	ARS_Modul
0x5A4	Dienste	services	0x24	CVM_V
0x5A5	Dienste	services	0x25	RSC_VDA/SC_CT/SC_VDA
0x5A7	Dienste	services	0x27	PGS
0x5A9	Dienste	services	0x29	DSC_CT/DSC_RB/DXC_RB
0x5B6	Dienste	services	0x36	TEL_BPI/TEL_JAP/TEL_MULF
0x5B7	Dienste	services	0x37	AMP_TOP
0x5B8	Dienste	services	0x38	EHC
0x5B9	Dienste	services	0x39	EDCK_Modul
0x5BA	Dienste	services	0x3A	KHM
0x5BB	Dienste	services	0x3B	JNAV
0x5BC	Dienste	services	0x3C	CDC
0x5BD	Dienste	services	0x3D	HUD
0x5C0	Dienste	services	0x40	CAS
0x5C1	Dienste	services	0x41	DWA
0x5C4	Dienste	services	0x44	MDS/SHD
0x5C5	Dienste	services	0x45	RLS/RLS
0x5CB	Dienste	services	0x4B	VM
0x5D0	Dienste	services	0x50	Notstrom-Sirene
0x5D3	Dienste	services	0x53	IBOC
0x5D4	Dienste	services	0x54	SDARS
0x5D5	Dienste	services	0x55	ISpeechBox
0x5D7	Dienste	services	0x57	NVC
0x5D9	Dienste	services	0x59	aLBV_FA
0x5DA	Dienste	services	0x5A	aLBV_BF
0x5DB	Dienste	services	0x5B	DAB
0x5DC	Dienste	services	0x5C	Behoerde
0x5DD	Dienste	services	0x5D	TLC
0x5DE	Dienste	services	0x5E	GWS
0x5DF	Dienste	services	0x5F	FLA
0x5E0	Dienste	services	0x60	Kombi
0x5E2	Dienste	services	0x62	CCC_GW/M_ASK
0x5E3	Dienste	services	0x63	CCC_MM
0x5E4	Dienste	services	0x64	PDC
0x5E5	Dienste	services	0x65	SZM/SZM_MIT_KBUS
0x5E7	Dienste	services	0x67	ZBE/ZBE_LO
0x5EB	Dienste	services	0x6B	HKL
0x5ED	Dienste	services	0x6D	SM_FA/SM_FA_KBUS
0x5EE	Dienste	services	0x6E	SM_BF/SM_BF_KBUS
0x5F0	Dienste	services	0x70	LM/LM_ALC
0x5F1	Dienste	services	0x71	AHM
0x5F2	Dienste	services	0x72	KBM
0x5F3	Dienste	services	0x73	CID_C/CID_C_H
0x5F8	Dienste	services	0x78	IHKA
0x5FA	Dienste	services	0x7A	SH_ZH
0x5FD	Dienste	services	0x7D	Diagnosetool_PT_CAN
0x5FE	Dienste	services	0x7E	Diagnosetool_K_CAN_System
0x609	Dienste	services	0x89	Xenon_Scheinwerfer_Links_ALC
0x60A	Dienste	services	0x8A	Xenon_Scheinwerfer_Rechts_ALC
0x60B	Dienste	services	0x8B	CNV
0x671	Dienste	services	0xF1	Diagnosedose
0x7C0	CAS Programmierung Bandende 1 (3)	CAS Programming Bandende 1 (3)	0x40	CAS
0x7C1	CAS Programmierung Bandende 2 (3)	CAS Programming Bandende 2 (3)	0xFF	TOOL_BANDENDE_CAS
0x7C2	CAS Applikationsnachricht 1 (3)	CAS Application Message 1 (3)	0x40	CAS
0x7C3	CAS Applikationsnachricht 2 (3)	CAS application message 2 (3)	0xFF	TOOL_BANDENDE_CAS
0xFFF	unbekannt	unknown	0xFF	Sender unbekannt

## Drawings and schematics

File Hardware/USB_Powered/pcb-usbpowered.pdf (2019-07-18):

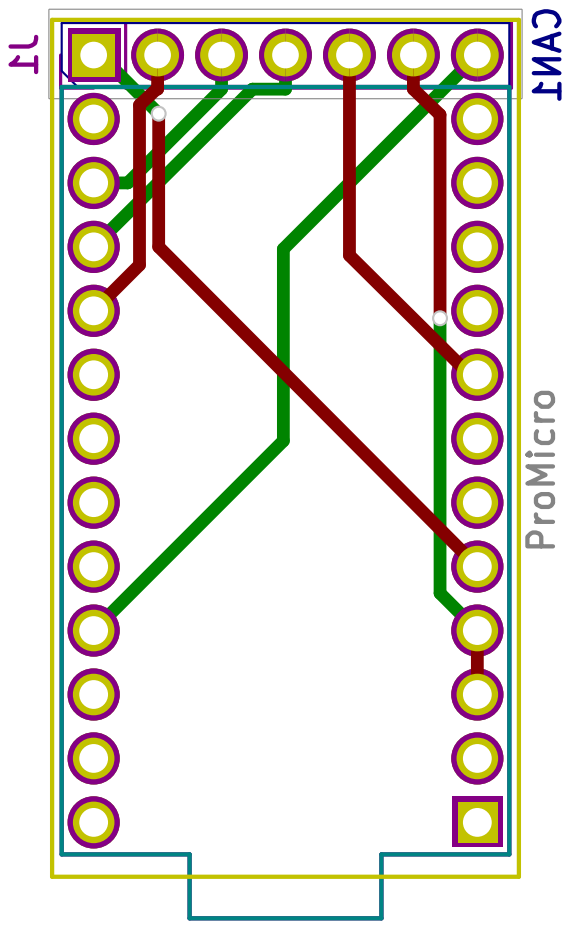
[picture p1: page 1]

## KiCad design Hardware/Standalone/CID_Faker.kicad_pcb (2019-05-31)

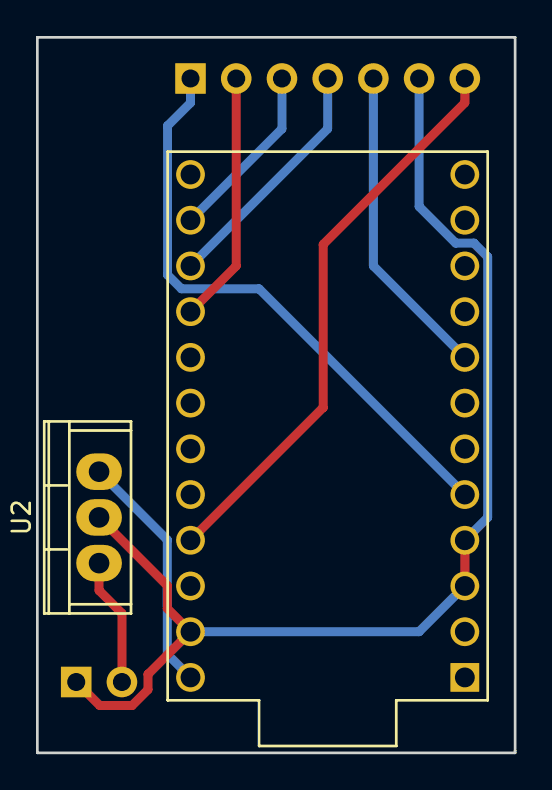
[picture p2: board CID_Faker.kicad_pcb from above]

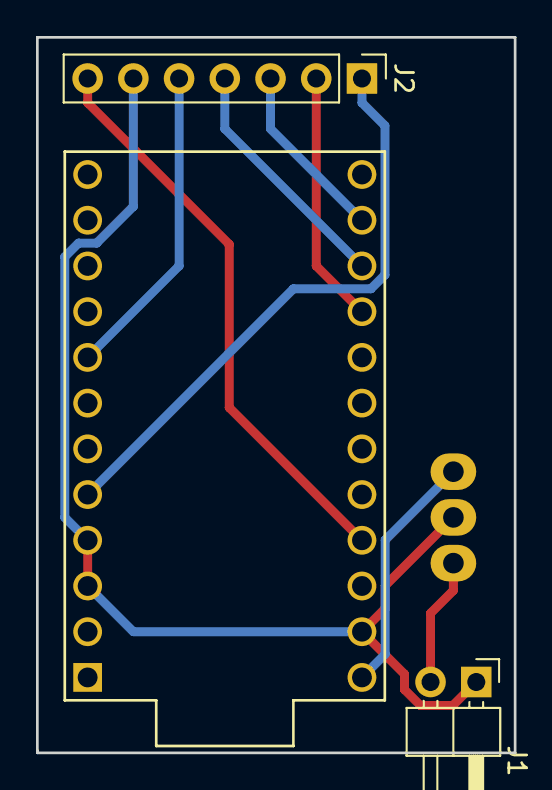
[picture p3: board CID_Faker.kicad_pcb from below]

Board: 2 copper layers, 26.5 x 39.8 mm, 4 parts (2 on the bottom side), 9 nets.

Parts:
J1: PWR; Pin_Header_Angled_1x02_Pitch2.54mm
J2: CAN; Socket_Strip_Straight_1x07_Pitch2.54mm
U1: ProMicro
U2: LF80_TO220; TO-220

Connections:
CS: J2.5, U1.8
GND: J1.1, J2.6, U1.3, U1.4, U1.23, U2.2
INT: J2.1, U1.5
MISO: J2.4, U1.15
MOSI: J2.3, U1.14
RAW: U1.24, U2.3
SCK: J2.2, U1.16
VCC: J2.7, U1.21
VIN: J1.2, U2.1

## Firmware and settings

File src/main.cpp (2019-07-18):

/*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
You should have received a copy of the GNU General Public License
along with this program.  If not, see <http://www.gnu.org/licenses/>.
*/
/*
  What it does and how it works :
  The Original (genuine) BMW CID sends on the CAN bus network 2 id messages
  status and network, status giving the screen health status and network the
  state of the motorized screen (opening/opened/closing/closed).
  This code makes the arduino send both id messages with the same timings that
  with the original screen, simulating its presence on the CAN bus network of
  the car:
  - 0x33a (status) is sent by 3 packets separated by 160ms, and repeated each
    10030ms.
  - 0x4f3 (network) is sent regularly each 940ms.
  These values/refresh rates where observed in my car (BMW e87 from 2005).
  The code was made with the goal to be able to modify easily the rates,
  timings and packet type to inject.
  To change rates and timings, simply read and edit framcecycletable.
  To add new packet type, declare a new t_canpacket, and add its pointer with its
  rate and timing to the framcecycletable.
 */

#include <Arduino.h>
#include <mcp_can.h>
#include <SPI.h>

# define CAN_CS   5
# define LED      17
# define MAX_TX_ERRS 3

typedef struct      canpacket
{
  unsigned long     id;
  uint8_t           len;
  uint8_t           data[8];
}                   t_canpacket;


typedef struct	framecycle
{
  unsigned long	start;
  unsigned long	cycletime;
  t_canpacket	*packet;
}		t_framecycle;

t_canpacket status = {0x33a, 5, {0x30, 0x82, 0x81, 0x0a, 0x7f, 0, 0, 0}};
t_canpacket network = {0x4f3, 8, {0x78, 0x42, 0xff, 0xff, 0xff, 0xff, 0xff, 0xff}};


// PROD VALUES
t_framecycle	framecycletable[] = 
  {
    {0, 10030, &status},
    {160, 10030, &status},
    {380, 10030, &status},
    {0, 940, &network},
    {0, 0, NULL}
  };

MCP_CAN CANDEV(CAN_CS);

void Error_loop(uint8_t count, uint16_t time)
{
  uint8_t i;

  for (i = 0; i < count; i++)
  {
    digitalWrite(LED, LOW);
    delay(time);
    digitalWrite(LED, HIGH);
    delay(time);
  }
    digitalWrite(LED, LOW);
}

bool		send_packet(INT32U id, INT8U len, INT8U *data)
{
  uint8_t	timeout = 0;

  while (CANDEV.sendMsgBuf(id, len, data) != CAN_OK && timeout <= MAX_TX_ERRS)
     timeout++;
  if (timeout >= MAX_TX_ERRS)
    return (false);
  else
    return (true);
}

void            setup()
{
  unsigned long inittime;

  pinMode(LED, OUTPUT);
  while (CANDEV.begin(MCP_ANY, CAN_100KBPS, MCP_8MHZ) != CAN_OK)
    Error_loop(5, 2000);
  CANDEV.setMode(MCP_NORMAL);
  inittime = millis();
  for (uint8_t i = 0; framecycletable[i].packet != NULL; i++)
    framecycletable[i].start += inittime;
}

void loop()
{
  digitalWrite(LED, LOW);
  for (uint8_t i = 0; framecycletable[i].packet != NULL; i++)
    if (framecycletable[i].start <= millis())
      {
        if (send_packet(framecycletable[i].packet->id, framecycletable[i].packet->len, framecycletable[i].packet->data) == true)
          digitalWrite(LED, (i % 2 ? LOW : HIGH));
        framecycletable[i].start = framecycletable[i].start + framecycletable[i].cycletime;
      }
  delay(5);
}

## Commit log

2019-06-01 changed to other mcp2515 lib seems old one does not work correctly on 8Mhz MCP @100kbps
    [main.cpp]
2019-06-01 corrected "visual" bug on error signaling
    [main.cpp]
2019-06-02 - changed timeout in can lib : from 50 to 100 : 50 not adapted to 100kbps@8Mhz - changed main table send loop to do retries if not sent correctly - TESTED WORKING :D
    [main.cpp]
2019-06-05 created 2 hardware profiles :
    - USB Powered : will contain a light version, that will use a usb port from android
    if android boots (ignition) it will automatically boot
    if android stops (car key off) it will automatically turn off the arduino
    - Standalone : a "standalone" version, allowing to have it "distant" from the android HU
    it will be up to the user to find a power cable were to connect it (RAW battery or other)
    [CID_Faker.kicad_pcb, CID_Faker.sch]
2019-06-07 cleared a bit the code corrected aesthetical bug on activity led ...
    [main.cpp]
2019-06-07 Had more time to really code at last one hour of coding and debugging: - corrected a dirty error on conditions - removed useless tests, variables and piece of code by changing a bit the algorithm - o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
    ... what else ?! :p
    [main.cpp]
2019-06-07 Corrected a "potential" bug : if for some reason, it could not send packets during a given period of time it would send them all in one when connection would be established again if for some reason i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
    [main.cpp]
2019-06-07 Updated USB powered version schematics
    [CID_Faker.dsn, CID_Faker.kicad_pcb, CID_Faker.sch]
2019-06-08 Corrected timing error at init in algorithm
    [main.cpp]
2019-06-14 upgraded to kicad 5 updated schematics and PCB
    [CID_Faker.kicad_pcb, CID_Faker.sch]
2019-06-15 Updated schema : longer but smaller ^^' (possibility to solder arduino and mcp module directly without header connectors)
    [CID_Faker.dsn, CID_Faker.kicad_pcb, CID_Faker.sch]
2019-06-17 Update main.cpp
    removed "ugly" semantic error ^^'
    [main.cpp]
2019-07-18 added a PDF view of the usbpowered schematic for simpler pinout connection view

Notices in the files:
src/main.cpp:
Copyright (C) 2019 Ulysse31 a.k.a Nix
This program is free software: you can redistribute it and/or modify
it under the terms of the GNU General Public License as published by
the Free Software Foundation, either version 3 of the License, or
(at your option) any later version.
